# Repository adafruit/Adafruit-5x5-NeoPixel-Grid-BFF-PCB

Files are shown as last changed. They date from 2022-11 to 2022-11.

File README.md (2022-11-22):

## Adafruit 5x5 NeoPixel Grid BFF PCB

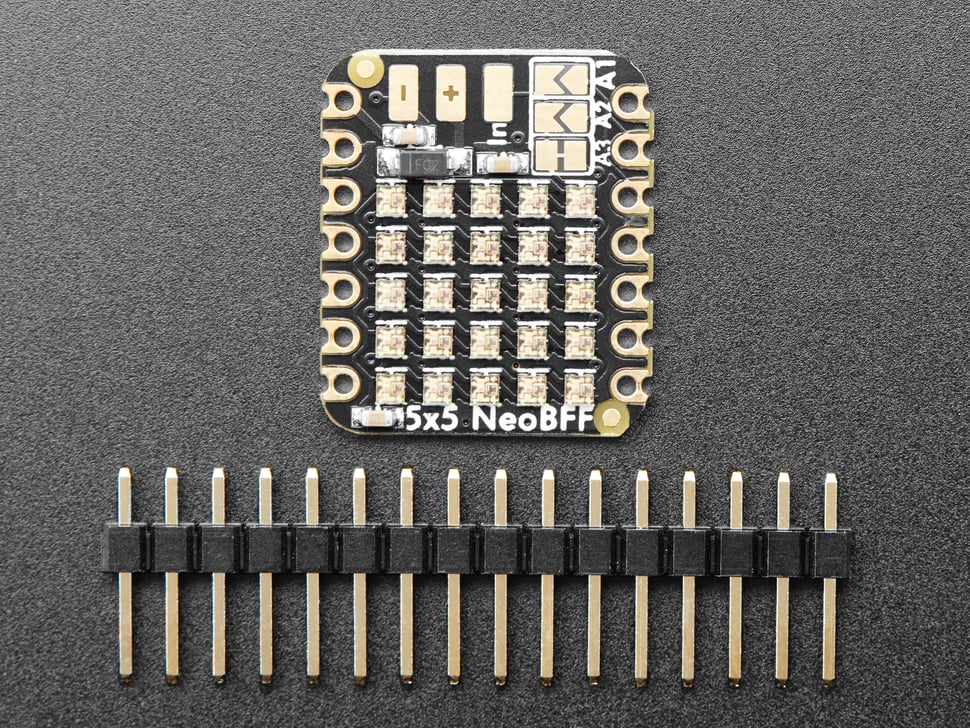
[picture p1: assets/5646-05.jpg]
<a href="http://www.adafruit.com/products/5646"><br/>
Click here to purchase one from the Adafruit shop</a>

PCB files for the Adafruit 5x5 NeoPixel Grid BFF. 

Format is EagleCAD schematic and board layout
* https://www.adafruit.com/product/5646

### Description

Our QT Py boards are a great way to make very small microcontroller projects that pack a ton of power - and now we have a way for you to quickly add a glittering grid of 25 RGB addressable micro NeoPixels. It's an excellent way to make tiny wearable, cosplay, or IoT projects with dazzling LEDs.

We call this the Adafruit 5x5 NeoPixel Grid BFF - a "Best Friend Forever". When you were a kid you may have learned about the "buddy" system, well this product is kinda like that! A board that will watch your QT Py's back and act like a technicolor raincoat.

This PCB is designed to fit onto the back of any QT Py or Xiao board, it can be soldered into place or use pin and socket headers to make it removable. Onboard is a grid of 25 1.5x1.5mm NeoPixel LEDs (SK6805 to be exact), connected to pin A3 by default. You can cut/solder some jumpers to select A1, or A2 instead if you like. There's also solder pads for 5V, GND and IN data, in case you want to power externally. Advanced solderer's can use a thin wire to connect from the IN pad to other GPIO pins if desired.

We include some header that you can solder to your QT Py. You can also pick up an Itsy Bitsy short female header kit to make it removable but compact, you'll just need to trim down the headers to 7 pins long.

Comes as an assembled and tested PCB
For any QT Py or Xiao boards
Uses the 5V input via USB Type-C connector on QT Py to Power 25 NeoPixels
Default connected to pin A3 for NeoPixel data line. Not level shifted but the SK6805's are happy to run at 5V power with 3V input logic level.
QT Py is not included.

### License

Adafruit invests time and resources providing this open source design, please support Adafruit and open-source hardware by purchasing products from [Adafruit](https://www.adafruit.com)!

Designed by Limor Fried/Ladyada for Adafruit Industries.

Creative Commons Attribution/Share-Alike, all text above must be included in any redistribution. 
See license.txt for additional details.

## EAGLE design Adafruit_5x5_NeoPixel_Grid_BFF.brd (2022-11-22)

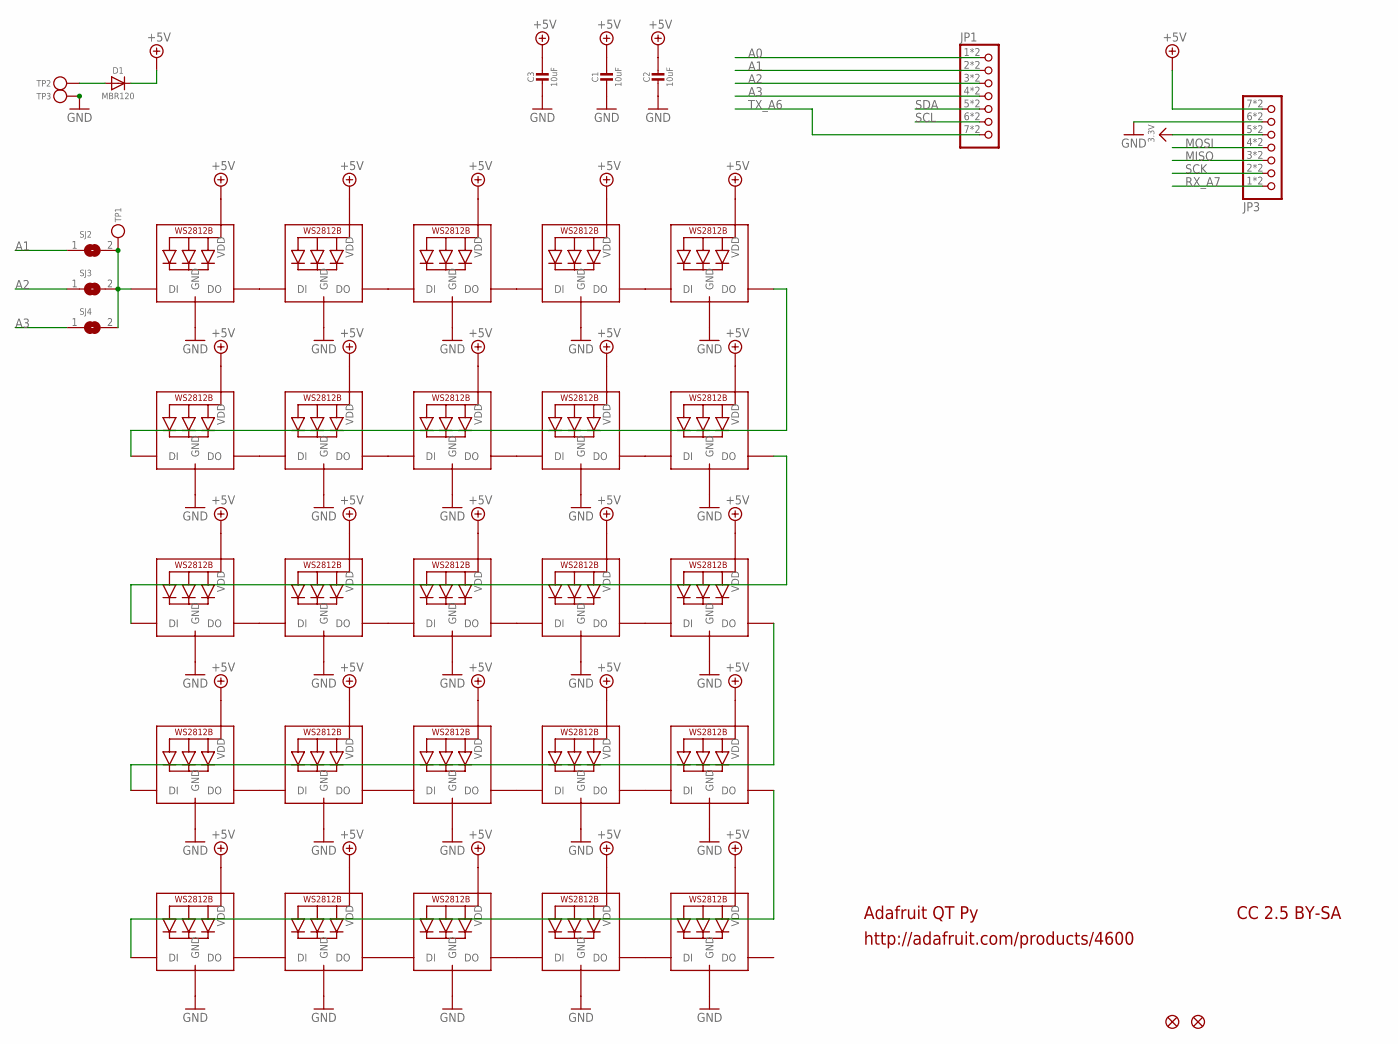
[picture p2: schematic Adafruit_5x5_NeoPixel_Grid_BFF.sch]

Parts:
C1, C2, C3: 10uF; 0603-NO
D1: MBR120; SOD-123
JP1, JP3: HEADER-1X7_CASTEL; 1X07_CASTEL
LED1, LED2, LED3, LED4, LED5, LED6, LED7, LED8, LED9, LED10, LED11, LED12, LED13, LED14, LED15, LED16, LED17, LED18, LED19, LED20, LED21, LED22, LED23, LED24, LED25: WS2812B_SK6805_1515; SK6805_1515
SJ2, SJ3: SOLDERJUMPER; SOLDERJUMPER_ARROW_NOPASTE
SJ4: SOLDERJUMPERCLOSED; SOLDERJUMPER_CLOSEDWIRE
TP1: TESTPOINT_1X3; TESTPOINT_RECT_1X3MM
TP2: TESTPOINT_PLUS13; TESTPOINT_PLUS_1X3MM
TP3: TESTPOINT_MINUS; TESTPOINT_MINUS_1X3MM
U$6, U$8: FIDUCIAL_1MM

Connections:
3.3V: JP3.5, JP3.5C (5)
+5V: C1.1, C2.1, C3.1, D1.C, JP3.7, JP3.7C (7), LED1.2 (VDD), LED2.2 (VDD), LED3.2 (VDD), LED4.2 (VDD), LED5.2 (VDD), LED6.2 (VDD), LED7.2 (VDD), LED8.2 (VDD), LED9.2 (VDD), LED10.2 (VDD), LED11.2 (VDD), LED12.2 (VDD), LED13.2 (VDD), LED14.2 (VDD), LED15.2 (VDD), LED16.2 (VDD), LED17.2 (VDD), LED18.2 (VDD), LED19.2 (VDD), LED20.2 (VDD), LED21.2 (VDD), LED22.2 (VDD), LED23.2 (VDD), LED24.2 (VDD), LED25.2 (VDD)
A0: JP1.1, JP1.1C (1)
A1: JP1.2, JP1.2C (2), SJ2.1
A2: JP1.3, JP1.3C (3), SJ3.1
A3: JP1.4, JP1.4C (4), SJ4.1
GND: C1.2, C2.2, C3.2, JP3.6, JP3.6C (6), LED1.4 (GND), LED2.4 (GND), LED3.4 (GND), LED4.4 (GND), LED5.4 (GND), LED6.4 (GND), LED7.4 (GND), LED8.4 (GND), LED9.4 (GND), LED10.4 (GND), LED11.4 (GND), LED12.4 (GND), LED13.4 (GND), LED14.4 (GND), LED15.4 (GND), LED16.4 (GND), LED17.4 (GND), LED18.4 (GND), LED19.4 (GND), LED20.4 (GND), LED21.4 (GND), LED22.4 (GND), LED23.4 (GND), LED24.4 (GND), LED25.4 (GND), TP3.P$1
MISO: JP3.3, JP3.3C (3)
MOSI: JP3.4, JP3.4C (4)
unnamed: LED1.3 (DO), LED2.1 (DI)
unnamed: LED2.3 (DO), LED3.1 (DI)
unnamed: LED3.3 (DO), LED4.1 (DI)
unnamed: LED4.3 (DO), LED5.1 (DI)
unnamed: LED6.3 (DO), LED7.1 (DI)
unnamed: LED7.3 (DO), LED8.1 (DI)
unnamed: LED8.3 (DO), LED9.1 (DI)
unnamed: LED9.3 (DO), LED10.1 (DI)
unnamed: LED11.3 (DO), LED12.1 (DI)
unnamed: LED12.3 (DO), LED13.1 (DI)
unnamed: LED13.3 (DO), LED14.1 (DI)
unnamed: LED14.3 (DO), LED15.1 (DI)
unnamed: LED16.3 (DO), LED17.1 (DI)
unnamed: LED17.3 (DO), LED18.1 (DI)
unnamed: LED18.3 (DO), LED19.1 (DI)
unnamed: LED19.3 (DO), LED20.1 (DI)
unnamed: LED21.3 (DO), LED22.1 (DI)
unnamed: LED22.3 (DO), LED23.1 (DI)
unnamed: LED23.3 (DO), LED24.1 (DI)
unnamed: LED24.3 (DO), LED25.1 (DI)
unnamed: LED5.3 (DO), LED6.1 (DI)
unnamed: LED10.3 (DO), LED11.1 (DI)
unnamed: LED15.3 (DO), LED16.1 (DI)
unnamed: LED20.3 (DO), LED21.1 (DI)
unnamed: LED1.1 (DI), SJ2.2, SJ3.2, SJ4.2, TP1.P$1
unnamed: D1.A, TP2.P$1
RX_A7: JP3.1, JP3.1C (1)
SCK: JP3.2, JP3.2C (2)
SCL: JP1.6, JP1.6C (6)
SDA: JP1.5, JP1.5C (5)
TX_A6: JP1.7, JP1.7C (7)

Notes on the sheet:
Adafruit QT Py
http://adafruit.com/products/4600
CC 2.5 BY-SA

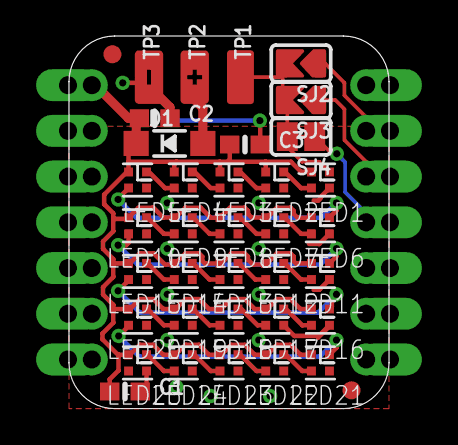
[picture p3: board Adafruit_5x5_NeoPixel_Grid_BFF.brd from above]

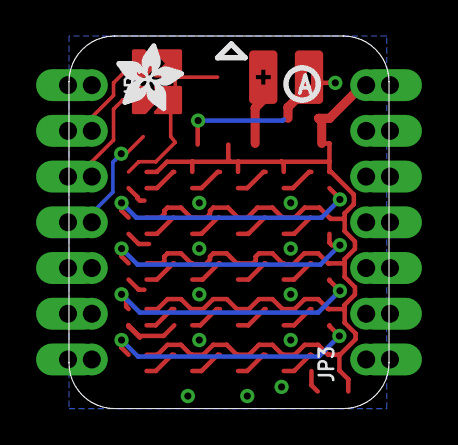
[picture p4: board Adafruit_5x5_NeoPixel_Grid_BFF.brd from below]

Board: 2 copper layers, 17.8 x 20.7 mm, 48 parts (6 on the bottom side), 40 nets.

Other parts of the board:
E$1: PCBFEAT-REV-040
E$3: ADAFRUIT_3.5MM
PLABEL0: PLABEL0
PLABEL2: PLABEL2
PLABEL3: PLABEL3
PLABEL4: PLABEL4
PLABEL5: PLABEL5
PLABEL7: PLABEL7
PLABEL8: PLABEL8

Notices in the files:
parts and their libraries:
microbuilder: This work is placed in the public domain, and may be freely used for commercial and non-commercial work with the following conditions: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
